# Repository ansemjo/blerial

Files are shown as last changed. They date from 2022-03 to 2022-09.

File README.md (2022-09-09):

# BLErial v1

Carrier board for a transparent Bluetooth 5.0 BLE to UART bridge based on [JiNan Huamao HM-17 modules](http://www.jnhuamao.cn/bluetooth.asp).

There is loads of such modules on Aliexpress and elsewhere. However, what sets this module apart is the CR2032 coin cell battery on the bottom side, which provides enough juice to power the board before it is physically connected to any device – allowing you to connect the serial console already and capture the very first few packets, as soon as they come in. As soon as the target's VCC is connected, the 3.3 V regulator kicks in and a simple, very much *not* ideal diode "OR" picks the higher voltage of the two supplies. A [level shifter based on two N-channel MOSFETs](https://cdn-shop.adafruit.com/datasheets/AN10441.pdf) shifts the signal levels to whatever reference is given on VCC pin. Therefore the VCC connection is always required; maybe think of it more like a Vref.

## Bluetooth Modules

There are different modules which fit the footprint:

| Model | Bluetooth Version |
| ----- | --- |
| HM-19 | BLE 5.0 |
| HM-17 | BLE 5.0/4.2 |
| HM-13 | Dual Mode: 4.0 EDR + BLE |
| HM-11 | BLE 4.0 |

I have also successfully connected a JDY-31. This required a glued-on plastic shim and some bodge wires but as long as you can connect `GND`, `VCC`, `RX`, `TX` and some sort of status `LED`, you should be good to go.

## Assembly

During assembly you can use the [interactive BOM `ibom.html`](https://ansemjo.github.io/blerial/ibom.html) to see where each component goes. Due to space constraints I ommitted reference designators in the silkscreen layer. :grimacing:

## Connection

* For the BLE modules, you can use [Jakeler/ble-serial](https://github.com/Jakeler/ble-serial) to create a `/tmp/ttyBLE` device, which you can then use with your favourite serial terminal.
* Dual Mode or older Bluetooth 2.0 RFCOMM devices can be connected with `rfcomm bind ...`.
* On Android devices, you can use the [Serial Bluetooth Terminal app](https://play.google.com/store/apps/details?id=de.kai_morich.serial_bluetooth_terminal) to connect both "classic" and LE modules.

## Images

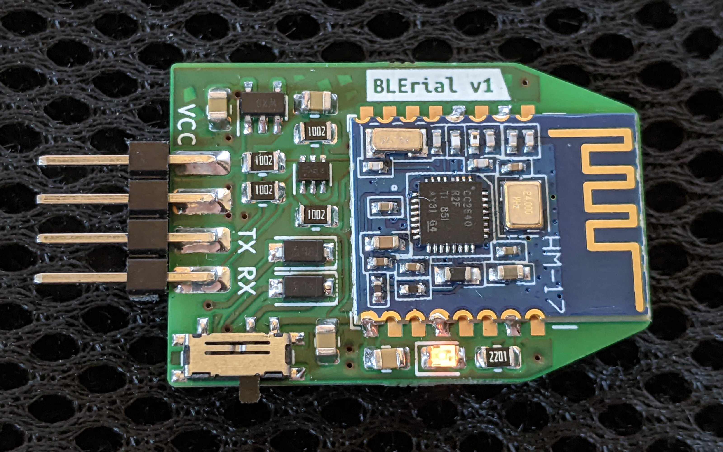
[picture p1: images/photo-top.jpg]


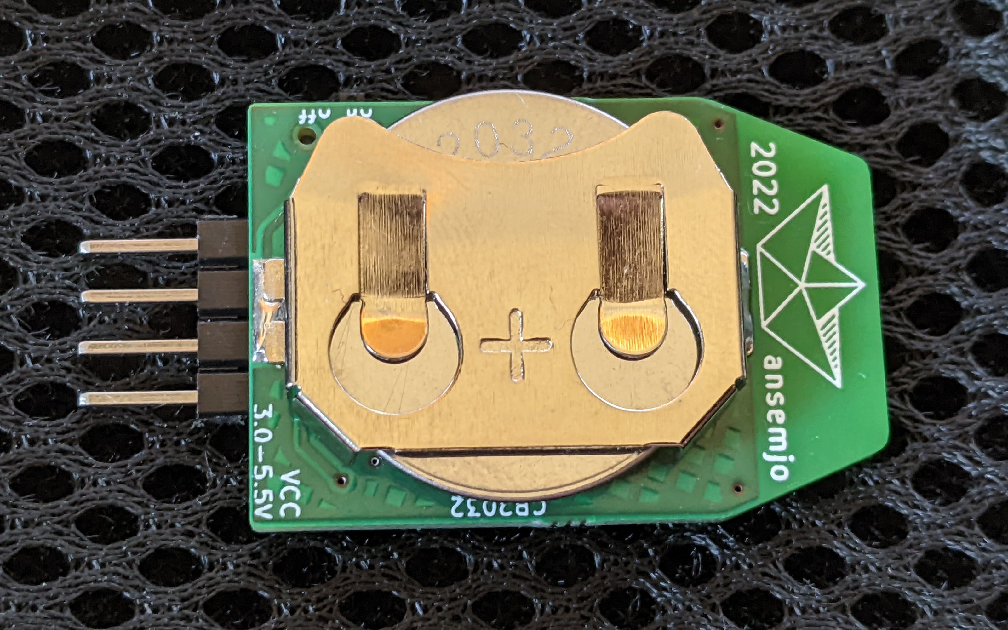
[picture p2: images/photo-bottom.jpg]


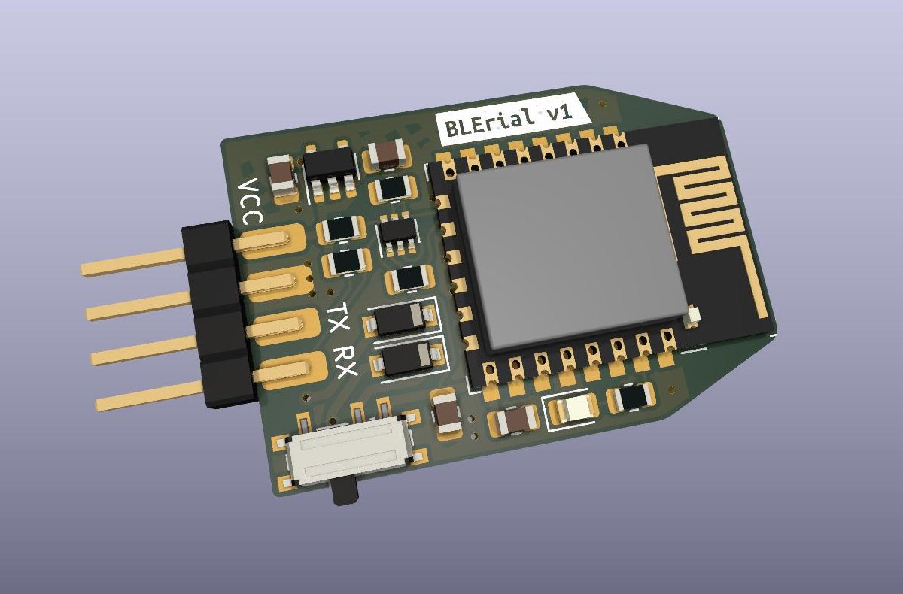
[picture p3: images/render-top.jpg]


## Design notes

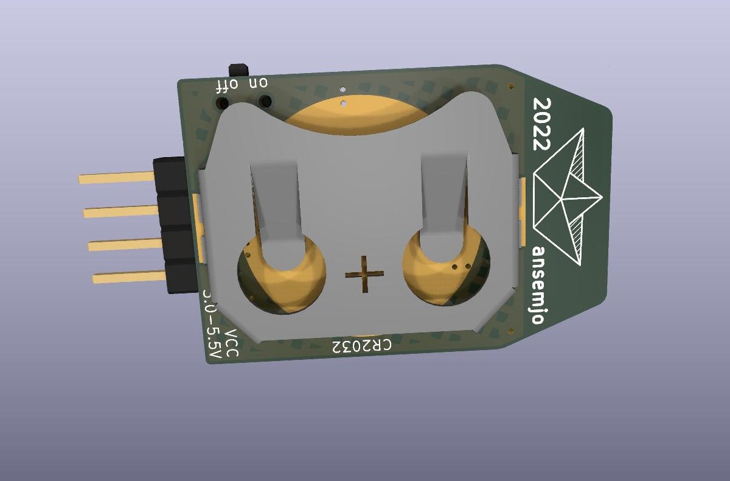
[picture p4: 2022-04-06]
images/render-bottom.jpg

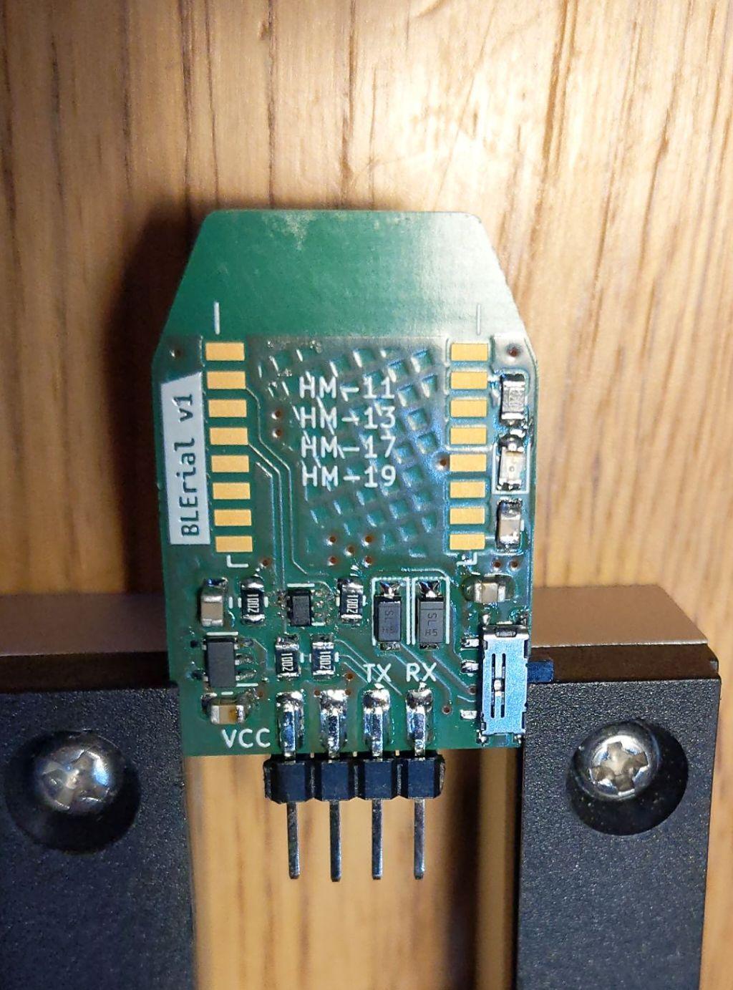
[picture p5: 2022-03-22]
images/photo-almost.jpg

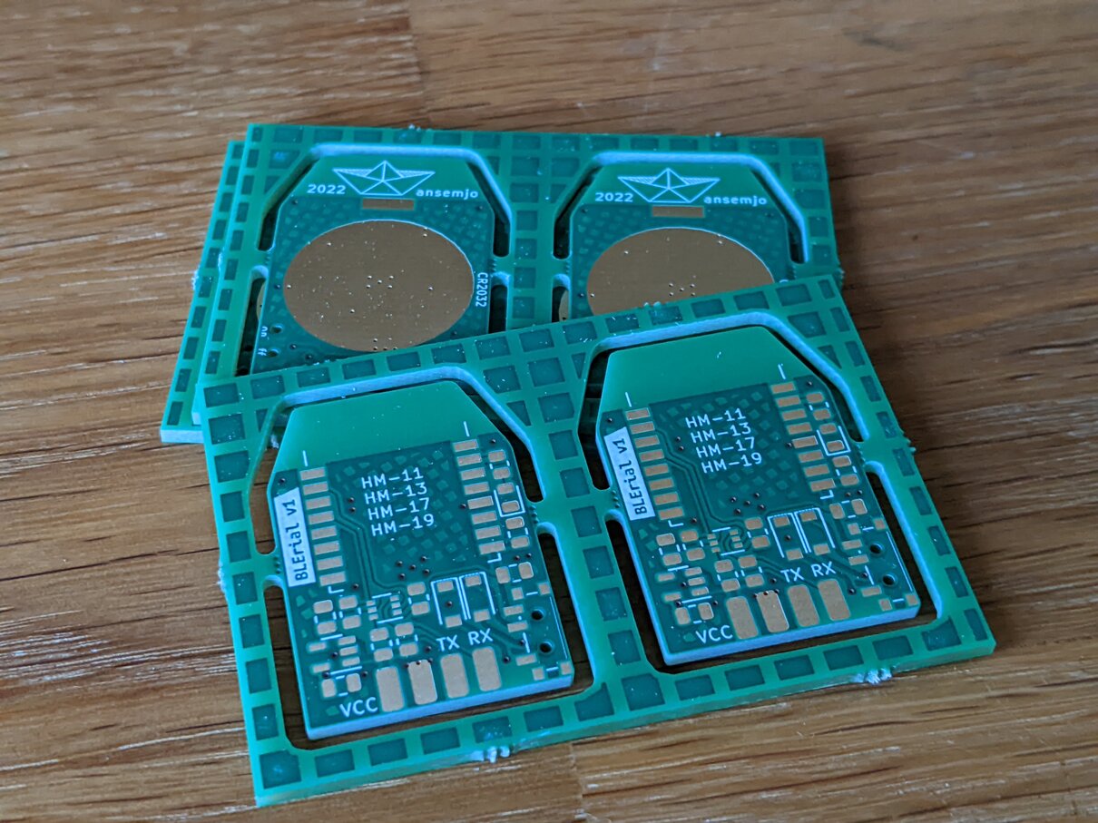
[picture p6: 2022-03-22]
images/photo-pcbs.jpg

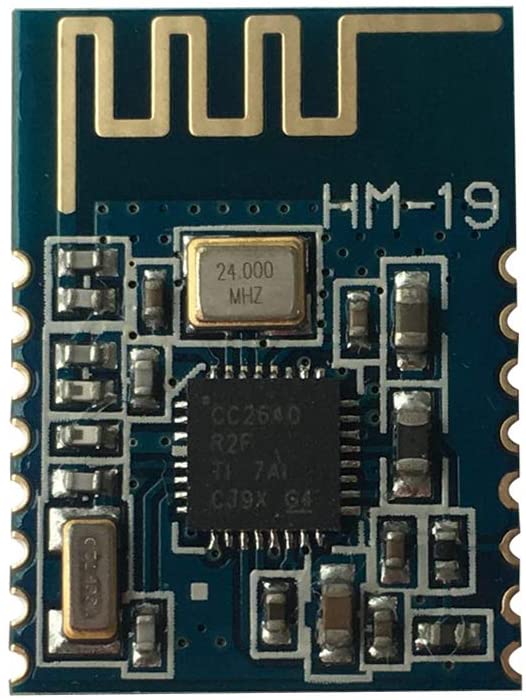
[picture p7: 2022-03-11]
datasheets/HM-19-module.jpg

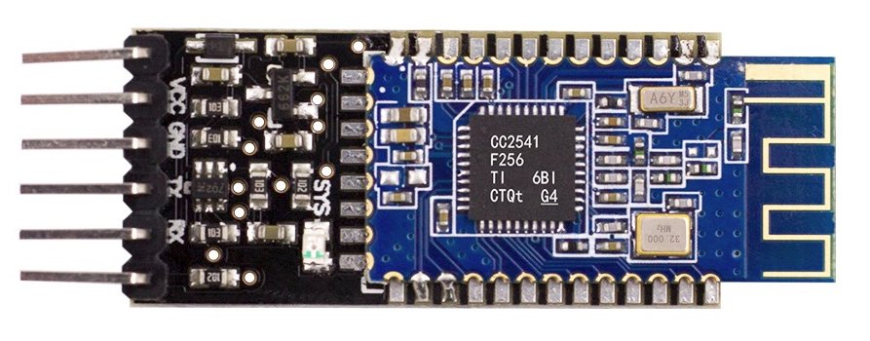
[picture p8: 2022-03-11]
datasheets/HM-10-breakout.jpg

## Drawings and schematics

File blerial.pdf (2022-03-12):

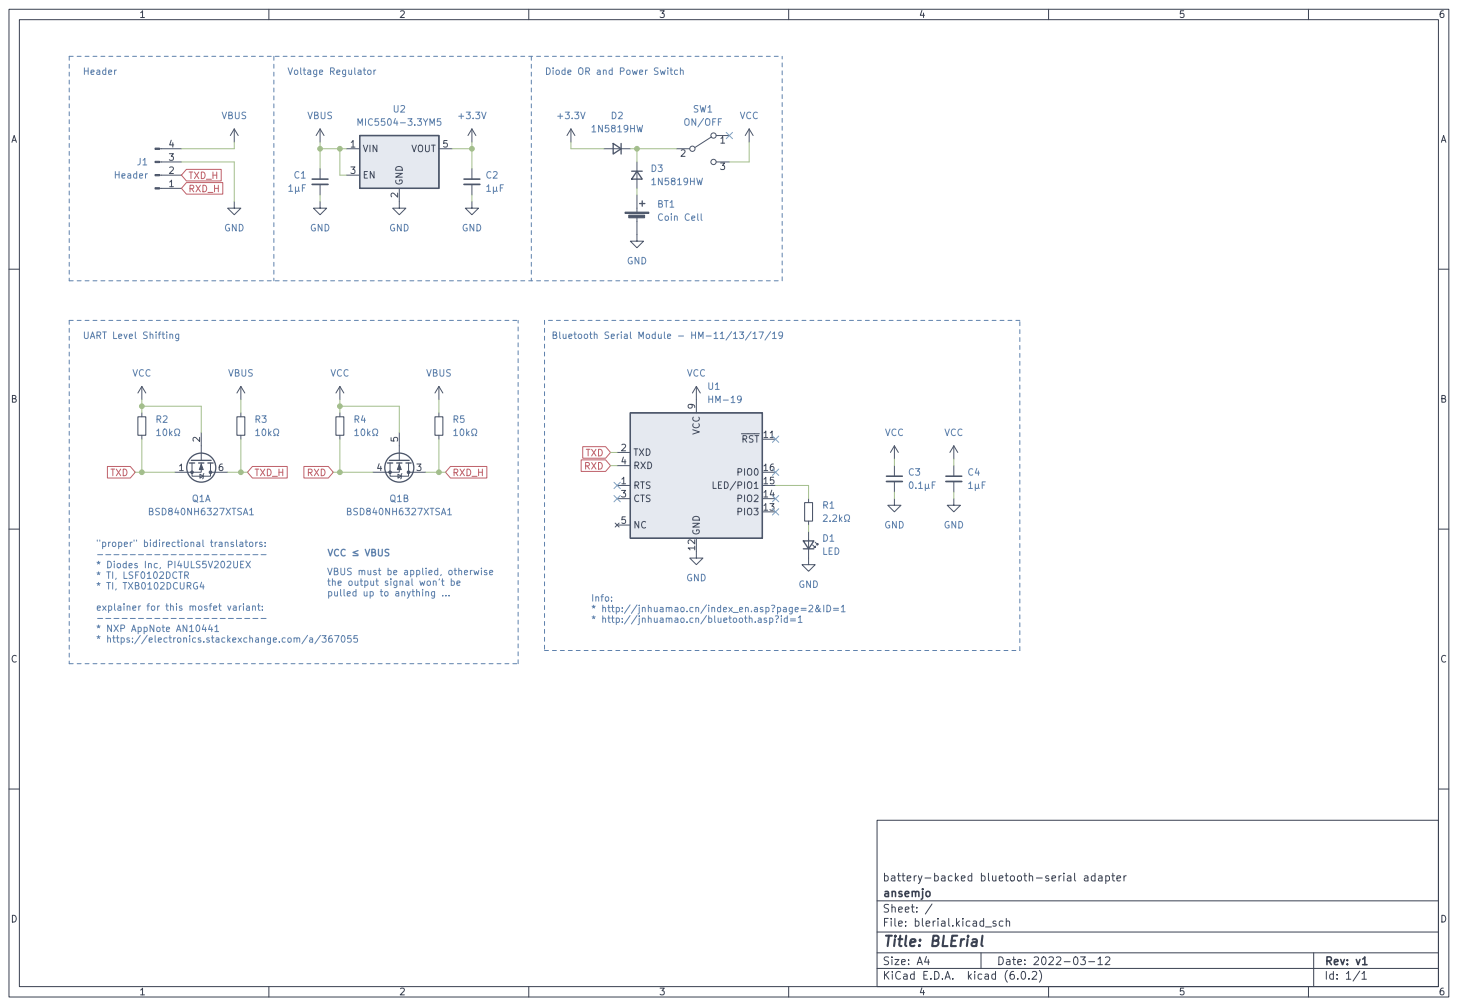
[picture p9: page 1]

Bluetooth Serial Module - HM-11/13/17/19

"proper" bidirectional translators: --------------------- * Diodes Inc, PI4ULS5V202UEX

the output signal won't be
pulled up to anything ...

Info: * http://jnhuamao.cn/index_en.asp?page=2&ID=1

explainer for this mosfet variant: --------------------- * NXP AppNote AN10441

* http://jnhuamao.cn/bluetooth.asp?id=1

* https://electronics.stackexchange.com/a/367055

battery-backed bluetooth-serial adapter
File: blerial.kicad_sch Sheet: / ansemjo

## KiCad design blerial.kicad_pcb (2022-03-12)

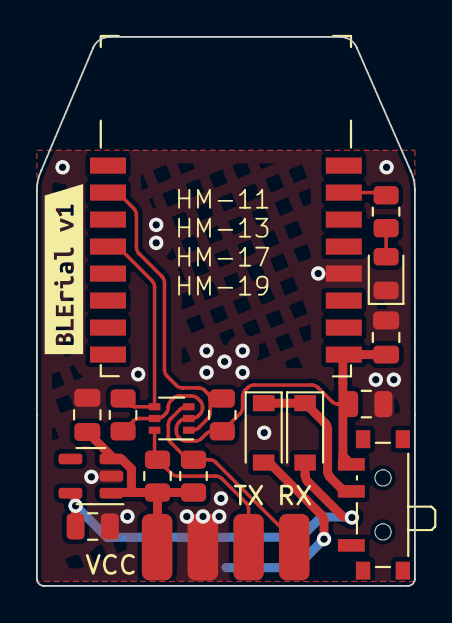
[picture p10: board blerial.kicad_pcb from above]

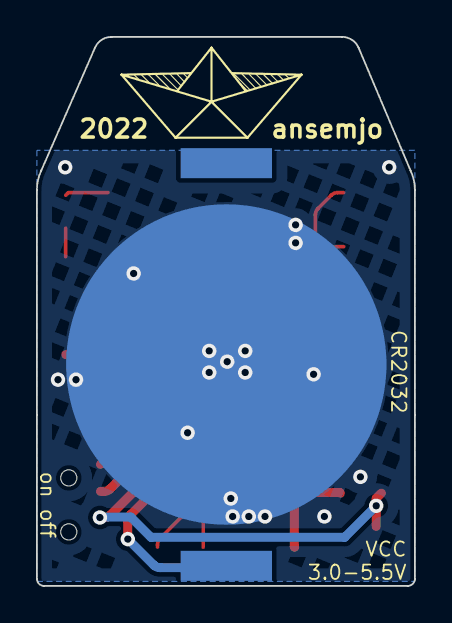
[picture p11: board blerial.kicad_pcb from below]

Board: 2 copper layers, 21.0 x 30.5 mm, 20 parts (2 on the bottom side), 12 nets.

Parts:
BT1: Coin Cell; BatteryHolder_Keystone_3034_1x20mm
C1, C2, C4: 1µF; C_0805_2012Metric
C3: 0.1µF; C_0805_2012Metric
D1: LED; LED_0805_2012Metric
D2, D3: 1N5819HW; D_SOD-123
J1: Header; PinHeader_1x04_P2.54mm_Horizontal
Q1: BSD840NH6327XTSA1; SOT-363_SC-70-6
R1: 2.2kΩ; R_0805_2012Metric
R2, R3, R4, R5: 10kΩ; R_0805_2012Metric
SW1: ON/OFF; SW_SPDT_PCM12
U1: HM-19
U2: MIC5504-3.3YM5; SOT-23-5
ahoi: 2022; ahoi
kibuzzard-622C9B09: G***; kibuzzard-622C9B09

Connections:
+3V3: C2.1, D2.2 (A), U2.5 (VOUT)
GND: BT1.2 (-), C1.2, C2.2, C3.2, C4.2, D1.1 (K), J1.3, U1.12 (GND), U2.2 (GND)
unnamed: BT1.1 (+), D3.2 (A)
unnamed: D1.2 (A), R1.1
unnamed: D2.1 (K), D3.1 (K), SW1.2 (B)
unnamed: R1.2, U1.15 (LED/PIO1)
RXD: Q1.4 (S), R4.2, U1.4 (RXD)
RXD_H: J1.1, Q1.3 (D), R5.2
TXD: Q1.1 (S), R2.2, U1.2 (TXD)
TXD_H: J1.2, Q1.6 (D), R3.2
VBUS: C1.1, J1.4, R3.1, R5.1, U2.1 (VIN), U2.3 (EN)
VCC: C3.1, C4.1, Q1.2 (G), Q1.5 (G), R2.1, R4.1, SW1.3 (C), U1.9 (VCC)

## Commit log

2022-02-21 begin tracking bluetooth serial board
    [blerial.kicad_pcb, blerial.kicad_sch, blerial.sch]
2022-02-21 edit to switch between bat / 3.3 regulator
    [blerial.kicad_pcb, blerial.kicad_sch]
2022-03-11 rerouted for HM-19, but not very tidy
    [blerial.kicad_pcb, blerial.kicad_sch, mosfet-comparison.ods]
2022-03-12 finished redesign with 200µm net class, rotated battery
    [blerial.kicad_pcb, blerial.kicad_sch]
2022-03-12 small tweaks, correct diode and mosfet pns
    [blerial.kicad_pcb, blerial.kicad_sch]
2022-09-09 add link to online interactive bom
